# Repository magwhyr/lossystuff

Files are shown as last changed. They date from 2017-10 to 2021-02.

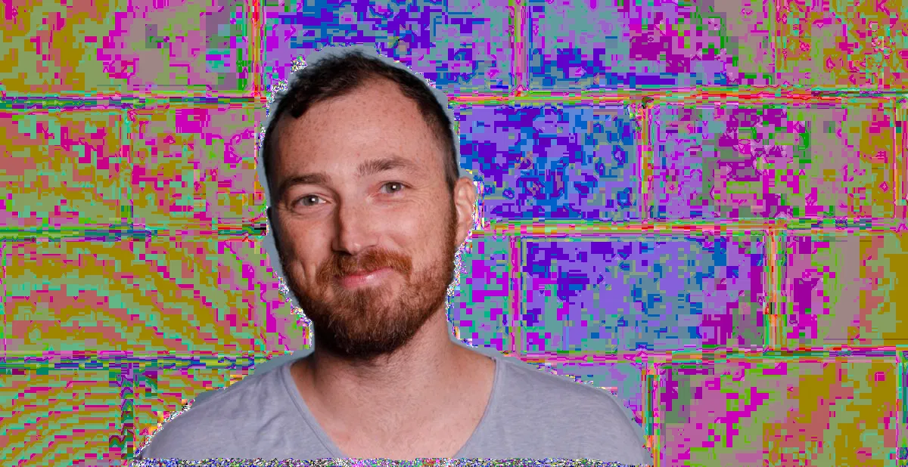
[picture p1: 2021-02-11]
rpmGhostRemix100.webp

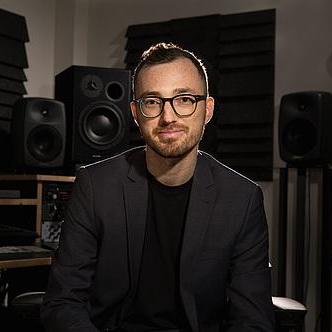
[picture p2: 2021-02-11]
ryan.jpg

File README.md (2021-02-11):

# lossystuff

# Step 1: buy hardware
## Hardware
* Raspberry Pi 3	
  * https://www.adafruit.com/product/3055
* potentiometer
  * https://www.sparkfun.com/products/9940
* volume knob (make sure it goes to 11)
  * https://www.sparkfun.com/products/11951
* ~~toggle switch~~
  * https://www.sparkfun.com/products/9276#reviews
  * Using a switch button instead
* 2.8" PiTFT capacitive screen
  * https://www.adafruit.com/product/2423
* PowerBoost charger
  * https://www.adafruit.com/product/2465
* 5V 2.4A Switching Power Supply
  * https://www.adafruit.com/product/1995
* Lithium Ion Polymer Battery - 3.7v 2500mAh
  * https://www.adafruit.com/product/328
* ~~MCP3008	Adafruit~~
  * https://www.adafruit.com/product/856
  * Using the ADS1115 instead because the PiTFT uses both SPI ports so I2C is the only thing left to use for potentiometer
* Samsung EVO 32GB Class 10 Micro SDHC Card with Adapter (MB-MP32DA/AM)
  * https://www.amazon.com/Samsung-Class-Adapter-MB-MP32DA-AM/dp/B00IVPU786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
* White LED Backlight Module - Medium 23mm x 75mm
  * https://www.adafruit.com/product/1622
* ~~Tactile Button switch (6mm)~~
  * https://www.adafruit.com/product/367
* USB A/MicroB
  * https://www.adafruit.com/product/898
* Audio extender
  * https://www.adafruit.com/product/3319
* ~~HDMI extender~~
  * https://www.amazon.com/gp/product/B001K38Z2G/
  * Not providing a port for HDMI after all. It doesn't work anyways with the PiTFT.
    * but, it does now when using the fbcp, but still not providing an HDMI port anyway.
* Mini Fan
  * https://www.adafruit.com/product/3368
* ADS1115 16-Bit ADC - 4 Channel with Programmable Gain Amplifier
  * https://www.adafruit.com/product/1085
* White LED Arcade Buttons
  * https://www.adafruit.com/product/3429
  * Four of them to provide different playbac options.
* Metal LED Blue On/Off Switch
  * https://www.adafruit.com/product/915
  * Switch for running the safe shutdown script.
* Metal LED Red On/Off Switch
  * https://www.adafruit.com/product/916
  * Power switch to turn on/off power from the PowerBoost

# Step 2: Install the OS on SD card
## OS Setup
* Follow the directions here to install Adafruit's modified Raspbian OS onto the SD card
  * https://learn.adafruit.com/adafruit-2-8-pitft-capacitive-touch/easy-install
* Follow these instructions for setting up WiFi on UVA network
  * http://scholarslab.org/makerspace/raspberry-pi-on-uva-wifi-network/
* Follow these instructions for configuring to use the PiTFT display
  * https://learn.adafruit.com/adafruit-2-8-pitft-capacitive-touch/overview

## OS Setup 2
* Begin with the PiTFT unplugged
* Follow instructions for installing the latest Raspbian OS.
  * https://www.raspberrypi.org/documentation/installation/
* Follow these instructions for setting up WiFi on UVA network
  * http://scholarslab.org/makerspace/raspberry-pi-on-uva-wifi-network/
* Follow instructions for installing fbcp
  * https://learn.adafruit.com/running-opengl-based-games-and-emulators-on-adafruit-pitft-displays/pitft-setup
  * For the options, select:
    1. Select Project: (option 4) Configure options manually
    2. Select display type: (option 3) PiTFT / PiTFT Plus 2.8" capacitive
    3. HDMI Rotation: (option 1) Normal
    4. TFT (MADCTL) rotation: (option 4) 270
  * Add this to the /boot/config.txt file to get the orientation for the touch to be correct.
    * `dtoverlay=pitft28-capacitive,rotate=270,touch-swapxy,touch-invy,speed=32000000,fps=20`
      * NOTE: you may need to have `touch-invx` instead of `touch-invy` if the mouse cursor is not behaving in the right direction.
    * http://www.0xf8.org/2016/01/complete-rotation-support-for-the-adafruit-pitft-2-8-capacitive-touchscreen-display/
    * http://www.runeaudio.com/forum/adafruit-pitft-2-8-capacitive-screen-with-buttons-solved-t3964.html
    * 
      ```
      # Enable audio (loads snd_bcm2835)
      dtparam=audio=on

      # PiTFT 2.8" settings
      dtoverlay=pitft28-capacitive,rotate=270,touch-swapxy,touch-invy,speed=32000000,fps=20
      display_rotate=0

      # Great resolution for just the PiTFT (too low for monitor)
      #hdmi_group=2
      #hdmi_mode=87
      # Great screen resolution for having the monitor attached
      hdmi_group=1
      hdmi_mode=34

      hdmi_cvt=320 240 60 1 0 0 0
      start_x=0
      ```
    * Change all occurances of hdmi_group to 2 and hdmi_mod to 87

### Using a monitor instead
To use a monitor instead of the PiTFT, you'll need to edit the `/boot/config.txt` file.
- Comment out the lines you add in from above, all of the lines that begin with "dtoverlay" and "display_rotate" and "hdmi_cvt"
- Make sure the monitor is plugged in via HDMI
- You can follow the steps here, under "Which values are valid for my monitor?", to determine which mode to use.
  - https://www.raspberrypi.org/documentation/configuration/config-txt/video.md
  - Edit the "hdmi_group" and "hdmi_mode" lines based on the results of the steps outlined above.
- Leave everything uncommented and both work at the same time.

# Step 3: Power

Power is improved with the PowerBoost. The PowerBoost connects to the Raspberry
Pi with a micro USB to USB A adapter (https://www.adafruit.com/product/898).
Power to the PowerBoost is provided by the Lithium Ion Polymer Battery - 3.7v
2500mAh (https://www.adafruit.com/product/328) or a wall adapter. An on/off
switch, also connected to the PowerBoost, cuts power to the PowerBoost and Pi.

* There are two switches to controll power on the Pi. One is a simple on/off
  switch that connects to the PowerBoost charger that cuts power to the
  Raspberry Pi. A button allows for safe shutdown of the Raspberry Pi.
* The PiTFT comes with four buttons on the side, one is wired to provide the
  safe shutdown. To free this button and use our own, follow this tutorial
  * Use this script. https://github.com/scruss/shutdown_button.git 
  * The button should be physically plugged into BCM/GPIO 27.
  * To run the shutdown script, the button must go from an unpressed to pressed state.
* To add the on/off switch to the PowerBoost, follow this tutorial
  * https://learn.adafruit.com/adafruit-powerboost-500-plus-charger/on-slash-off-switch
  * Basically, solder the two wire switch to the GND and EN holes
  * The switch (https://www.adafruit.com/product/916) has a built in LED, so wiring is as such: 
    * + to 5v on the PowerBoost, and - to the Gnd on PowerBoost. C1 (common) on switch to Gnd on PowerBoost. NO1 (Noncommon Open) on switch to En on PowerBoost.

* The Fan is also connected to the PowerBoost. The same Gnd and 5v as the switch so that the fan is on when the system is on and off when the system is off.

# Step 4: Volume Control (it goes to 11)
- Add this line to `/boot/config.txt` to remove hissing from the 3.5mm audio output
  - `audio_pwm_mode=2`
- Analog to digital conversion is handled with the ADS1115 16-Bit ADC - 4 Channel with Programmable Gain Amplifier (https://www.adafruit.com/product/1085) The amplifier sits between the Pi and a potentiometer (https://www.sparkfun.com/products/9940) with a volume knob (make sure it goes to 11) (https://www.sparkfun.com/products/11951).
  - The ADC is connected to the Raspberry Pi 3V and Ground, and SCL to SCL, and SDA to SDA.
  - The potentiometer is connected to the Raspberry Pi 3V and Ground, and the middle connection to A0 on the ADC.
- Get the Python libraries for connecting with ADC
  - https://github.com/adafruit/Adafruit_Python_ADS1x15
  -
    ```
    sudo apt-get install git build-essential python-dev
    cd ~
    git clone https://github.com/adafruit/Adafruit_Python_ADS1x15.git
    cd Adafruit_Python_ADS1x15
    sudo python setup.py install
    ```
- And the python library for controlling the volume
  - https://stackoverflow.com/questions/41592431/changing-volume-in-python-program-on-raspbery-pi
  -
  ```
  sudo apt-get install python-alsaaudio
  ```
- Make a file at ~/volume-control/volume-control.py to control the volume
  - 
    ```
      import time
      import alsaaudio
      import Adafruit_ADS1x15

      adc = Adafruit_ADS1x15.ADS1115()
      m = alsaaudio.Mixer('PCM')

      current_volume = m.getvolume()

      # Choose a gain of 1 for reading voltages from 0 to 4.09V.
      # Or pick a different gain to change the range of voltages that are read:
      #  - 2/3 = +/-6.144V
      #  -   1 = +/-4.096V
      #  -   2 = +/-2.048V
      #  -   4 = +/-1.024V
      #  -   8 = +/-0.512V
      #  -  16 = +/-0.256V
      # See table 3 in the ADS1015/ADS1115 datasheet for more info on gain.
      GAIN = 1

      def maprange(VOL, POT, v):
          (VOL1, VOL2), (POT1, POT2) = VOL, POT
          return  POT1 + ((v - VOL1) * (POT2 - POT1) / (VOL2 - VOL1))

      while True:
          value = adc.read_adc(0, gain=GAIN)
          volume = maprange((0,26354), (0,100), value)
          if volume < 0:
              volume = 0
          m.setvolume(volume)
    ```

- Add this line to `~/.config/lxsession/LXDE-pi/autostart` to have the python script run on startup.
  - `/usr/bin/python /home/pi/volume-control/volume-control.py`

# Step 5: Get Processing to run the script at boot
- Make sure the resolution on the PiTFT is max at 320x240.
- Add this line to `~/.config/lxsession/LXDE-pi/autostart`
  - `/home/pi/processing-3.3.6/processing-java --sketch=/home/pi/sketchbook/modernistPi --run`

# Step 6: Hardware Assembly

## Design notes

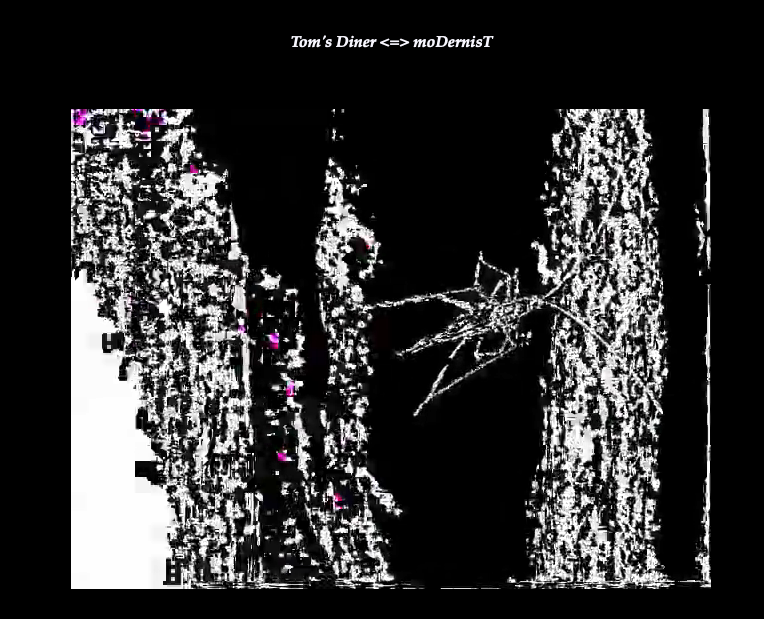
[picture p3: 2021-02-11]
moDernisT.png

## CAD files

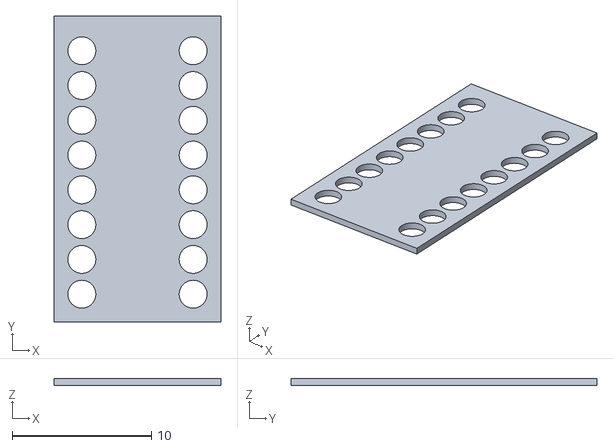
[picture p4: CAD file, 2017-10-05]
PCB for MCP3008/PCB for MCP3008.stl
12.0 x 22.0 x 0.5

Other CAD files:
PCB for MCP3008/tinker.obj

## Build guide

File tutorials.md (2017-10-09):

# Adding analog to raspberry pi
- for adding audio volume potentiometer
  - https://learn.adafruit.com/reading-a-analog-in-and-controlling-audio-volume-with-the-raspberry-pi/run-it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
  - https://www.raspberrypi-spy.co.uk/2014/08/enabling-the-spi-interface-on-the-raspberry-pi/
  - https://www.raspberrypi-spy.co.uk/2013/10/analogue-sensors-on-the-raspberry-pi-using-an-mcp3008/
  - http://www.knight-of-pi.org/reading-an-analog-potentiometer-with-the-ad-converter-mcp3008-and-spi/
  - https://www.raspberrypi.org/forums/viewtopic.php?f=9&t=5583
- Control OMX with python
  - https://github.com/jbaiter/pyomxplayer

# Playing video on the PiTFT screen
- https://learn.adafruit.com/adafruit-2-8-pitft-capacitive-touch/playing-videos

# Power switch for Raspberry Pi
- http://www.raspberry-pi-geek.com/Archive/2013/01/Adding-an-On-Off-switch-to-your-Raspberry-Pi
- http://willhaley.com/blog/power-off-raspberry-pi-adafruit-tft-screen-shutdown/

# Fan for Pi
- https://hackernoon.com/how-to-control-a-fan-to-cool-the-cpu-of-your-raspberrypi-3313b6e7f92c
 
# Clone SD card for easy reinstalls
- https://raspberrypi.stackexchange.com/questions/311/how-do-i-backup-my-raspberry-pi

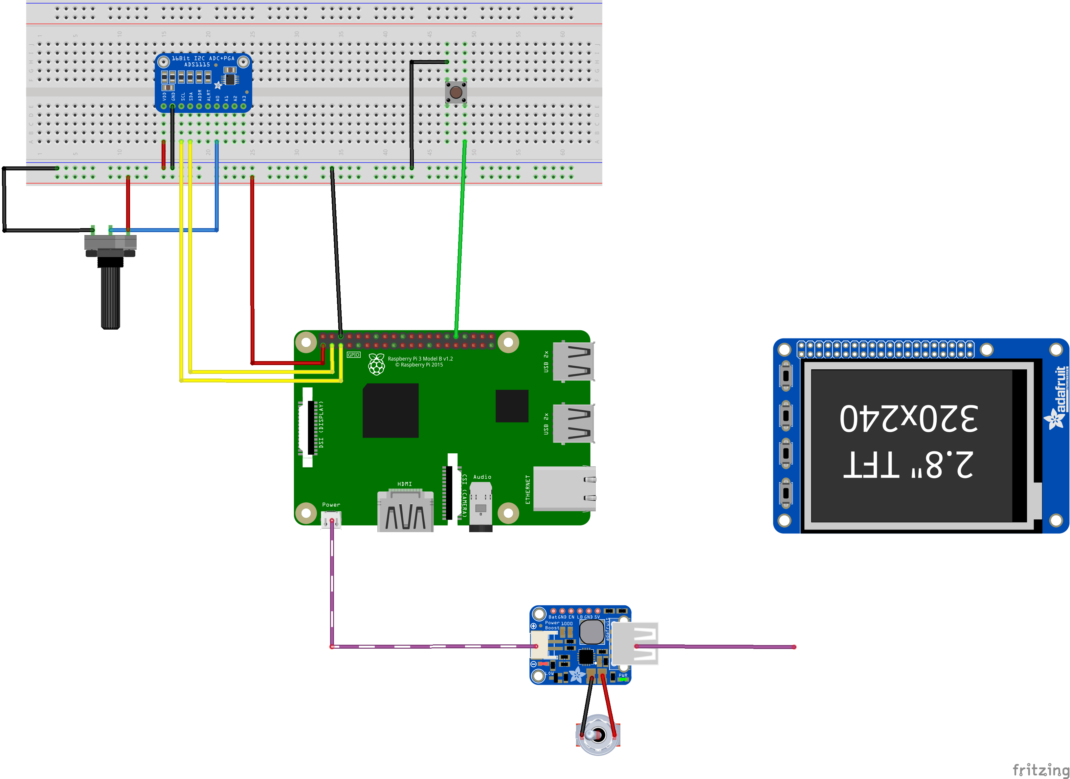
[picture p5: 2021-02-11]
wiring-diagram_bb.png

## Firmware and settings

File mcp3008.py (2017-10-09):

#!/usr/bin/env python

# Written by Limor "Ladyada" Fried for Adafruit Industries, (c) 2015
# This code is released into the public domain
# Source: git clone git://gist.github.com/3151375.git

import time
import os
import RPi.GPIO as GPIO

GPIO.setmode(GPIO.BCM)
DEBUG = 1

# read SPI data from MCP3008 chip, 8 possible adc's (0 thru 7)
def readadc(adcnum, clockpin, mosipin, misopin, cspin):
        if ((adcnum > 7) or (adcnum < 0)):
                return -1
        GPIO.output(cspin, True)

        GPIO.output(clockpin, False)  # start clock low
        GPIO.output(cspin, False)     # bring CS low

        commandout = adcnum
        commandout |= 0x18  # start bit + single-ended bit
        commandout <<= 3    # we only need to send 5 bits here
        for i in range(5):
                if (commandout & 0x80):
                        GPIO.output(mosipin, True)
                else:
                        GPIO.output(mosipin, False)
                commandout <<= 1
                GPIO.output(clockpin, True)
                GPIO.output(clockpin, False)

        adcout = 0
        # read in one empty bit, one null bit and 10 ADC bits
        for i in range(12):
                GPIO.output(clockpin, True)
                GPIO.output(clockpin, False)
                adcout <<= 1
                if (GPIO.input(misopin)):
                        adcout |= 0x1

        GPIO.output(cspin, True)
        
        adcout >>= 1       # first bit is 'null' so drop it
        return adcout

# change these as desired - they're the pins connected from the
# SPI port on the ADC to the Cobbler
SPICLK = 18
SPIMISO = 21
SPIMOSI = 5
SPICS = 6

# set up the SPI interface pins
GPIO.setup(SPIMOSI, GPIO.OUT)
GPIO.setup(SPIMISO, GPIO.IN)
GPIO.setup(SPICLK, GPIO.OUT)
GPIO.setup(SPICS, GPIO.OUT)

# 10k trim pot connected to adc #0
potentiometer_adc = 0;

last_read = 0       # this keeps track of the last potentiometer value
tolerance = 5       # to keep from being jittery we'll only change
                    # volume when the pot has moved more than 5 'counts'

while True:
        # we'll assume that the pot didn't move
        trim_pot_changed = False

        # read the analog pin
        trim_pot = readadc(potentiometer_adc, SPICLK, SPIMOSI, SPIMISO, SPICS)
        # how much has it changed since the last read?
        pot_adjust = abs(trim_pot - last_read)

        if DEBUG:
                print "trim_pot:", trim_pot
                print "pot_adjust:", pot_adjust
                print "last_read", last_read

        if ( pot_adjust > tolerance ):
               trim_pot_changed = True

        if DEBUG:
                print "trim_pot_changed", trim_pot_changed

        if ( trim_pot_changed ):
                set_volume = trim_pot / 10.24           # convert 10bit adc0 (0-1024) trim pot read into 0-100 volume level
                set_volume = round(set_volume)          # round out decimal value
                set_volume = int(set_volume)            # cast volume as integer

                print 'Volume = {volume}%' .format(volume = set_volume)
                set_vol_cmd = 'sudo amixer cset numid=1 -- {volume}% > /dev/null' .format(volume = set_volume)
                os.system(set_vol_cmd)  # set volume

                if DEBUG:
                        print "set_volume", set_volume
                        print "tri_pot_changed", set_volume

                # save the potentiometer reading for the next loop
                last_read = trim_pot

        # hang out and do nothing for a half second
        time.sleep(0.5)

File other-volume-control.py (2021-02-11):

#!/usr/bin/python
 
# Source: https://www.raspberrypi.org/forums/viewtopic.php?f=9&t=5583


import spidev
import time
import os
import math
from mpd import MPDClient

# Get Static Sound from MPD playlist


# Connect to MPD server
client = MPDClient()
client.timeout = 5
client.connect("localhost",6600)
#print client.playlistsearch("any","RadioTune.mp3")
for song in client.playlistsearch("any","RadioTune.mp3"): # Change this to the name of the audio 
  song_id = song["id"]					#file you want to play from MPD playlist
  song_time = song["time"]
  song_time = int(song_time) + 5

# Open SPI bus
spi = spidev.SpiDev()
spi.open(0,0)
 
# Function to read SPI data from MCP3008 chip
# Channel must be an integer 0-7
def ReadChannel(channel):
  adc = spi.xfer2([1,(8+channel)<<4,0])
  data = ((adc[1]&3) << 8) + adc[2]
  return data
 
# Function to convert data to voltage level,
# rounded to specified number of decimal places.
def ConvertVolts(data,places):
  volts = (data * 3.3) / float(1023)
  volts = round(volts,places)
  return volts
 
# Define sensor channels
vol_channel = 0
tune_channel = 1
#etc
 
# Define delay between readings
vol_delay = .5
tune_delay = 5
step = 0

# Define tolernances
vol_last_read = 0
tune_last_read = 0
vol_tolerance = 10
tune_tolerance = 5

while True:

  trim_pot_changed = False
  tune_pot_changed = False
 
  # Read the pot data
  vol_level = ReadChannel(vol_channel)
  vol_volts = ConvertVolts(vol_level,2)
  tune_level = ReadChannel(tune_channel)
  tune_volts = ConvertVolts(tune_level,2)

  tune_actual = (math.log(tune_level + 1,10) * 341) / 10.24
  tune_actual = round(tune_actual)
  tune_actual = int(tune_actual)

  vol_pot_adjust = abs(vol_level - vol_last_read)
  tune_pot_adjust = abs(tune_actual - tune_last_read)

  if ( vol_pot_adjust > vol_tolerance ):
    trim_pot_changed = True
  if ( tune_pot_adjust > tune_tolerance ):
    tune_pot_changed = True

  if ( trim_pot_changed ):
    # convert 10bit adc0 (0-1024) trim pot read into 0-100 volume level with LOG correction
    set_volume = (math.log(vol_level + 1,10) * 341) / 10.24
    set_volume = round(set_volume)          # round out decimal value
    set_volume = int(set_volume)            # cast volume as integer
 
    set_vol_cmd = 'sudo amixer cset numid=1 -- {volume}% > /dev/null' .format(volume = set_volume)
    os.system(set_vol_cmd)  # set volume
 
    # Print out results
    print "--------------------------------------------"
    print("Volts : {} ({}V)".format(vol_level,vol_volts))
    print "Volume: ", set_volume

    vol_last_read = vol_level

  if ( tune_pot_changed ): #is True and step >= tune_delay):

    # Print out results
    print "--------------------------------------------"
    print "Tuner Change Detected"

    # Play the tuner change sound
    client.playid(song_id)
    print "Start"
    time.sleep(song_time)
    print "Stop"
    tune_level = ReadChannel(tune_channel)
    tune_actual = (math.log(tune_level + 1,10) * 341) / 10.24
    tune_actual = round(tune_actual)
    tune_actual = int(tune_actual)
    tune_last_read = tune_actual

#    step = 0
#  else:
#    step = step + vol_delay

  # Wait before repeating loop

  time.sleep(vol_delay)

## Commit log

2017-06-29 Add link to fan tutorial.
2017-09-21 Adds 3D model files for a PCB for the MCP3008 IC.
    [PCB for MCP3008.stl, tinker.obj]
2017-09-21 Add tutorial for power switch.
2017-10-05 Reduce height to .25mm
    [PCB for MCP3008.stl, tinker.obj]
2017-12-12 Add info about the power switch and fan.
2017-12-13 Update hardware list, and shutdown button info.
2017-12-20 Add links to solving the PiTFT orientation. Update process of shutdown button.
2021-02-11 Add more steps to README and add python files
    [wiring-diagram.fzz]
